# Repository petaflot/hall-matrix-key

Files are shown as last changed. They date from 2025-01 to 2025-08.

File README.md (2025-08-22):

# Hall Jumper Selector Matrix

A tool to help getting the configuration of hall sensors correct for any arbitrary 3-phase electric motor fitted with such devices. There are 6 possible arrangements, for direct and inverse rotations, and shifts relative to the phases. A 2x04 matrix is sufficient to select each arrangement by connecting adjacent pins.

A document that gives [more information on the arrangements](hall-jumper-matrix.pdf) can be found here.

## Hall Key

A simple yet elaborate mechanical device to ease the task of finding the correct jumper configuration ; special care was taken to reduce wear on the sliding contacts and thus extend the device life.
It looks pretty and is a somewhat mystical object that you can carry around everywhere you go.

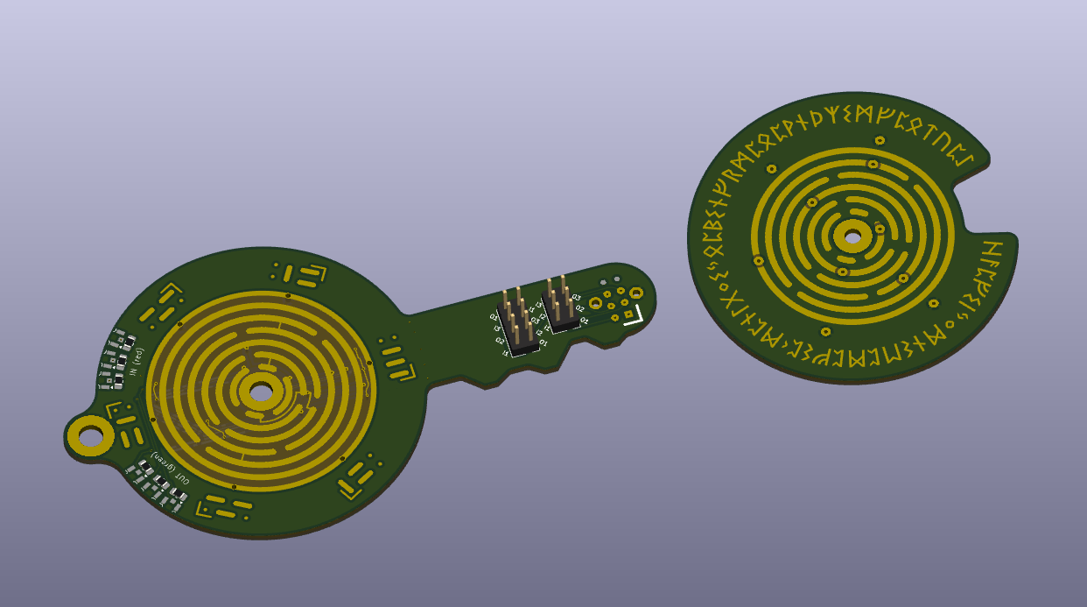
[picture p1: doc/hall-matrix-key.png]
Hall Key


***NOTE: In the above picture, the tracks are wrong ; this was fixed***

Datasheets of the required components are included.

### Note on the circular tracks

Considering the electrical and mechanical constraints, there is a unique solution to the arrangement ; therefore, it can be considered as a rune.

## Hall Matrix

A 2x04 pins jumper configuration matrix ; this project also includes a dedicated a solder jumper matrix footprint for Kicad. The pogo pins of the selector key go there, and they can be soldered once the correct configuration has been found.

***WARNING: footprint is not up-to-date with latest version of key!***

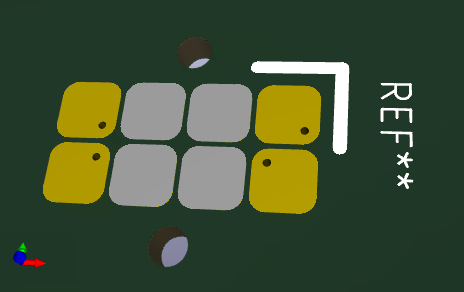
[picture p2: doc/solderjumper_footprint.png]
Solder jumper footprint


To ensure it can be accessed with the key, this footprint should go at the edge of the board.

An alternative is to use 2x04 header pins and regular jumpers ; this enables the configuration to be changed easily afterwards. In the case, connect to the key with a short cable.

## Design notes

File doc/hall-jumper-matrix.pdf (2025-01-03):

Feuille1

# Hall Sensor Selection Matrix

I1 | O2 | I3 | O1 ≃ | I1 | O2 | I3 | O1 | Norm
O1 | I2 | O3 | I1 | O1 | I2 | O3 | I1
I1 | O2 | I3 | O1 | | | | | Norm+1
O1 | I2 | O3 | I1
I1 | O2 I3 | O1 | Norm+2
O1 I2 | O3 I1
I1 | O2 | I3 | O1 | | | | | Rev-2
O1 | I2 | O3 I1
I1 | O2 | I3 | O1 | | | | | Rev-1
O1 I2 | O3 | I1
I1 | O2 I3 | O1 ≃ | I1 | O2 I3 | O1 | Rev
O1 | I2 | O3 | I1 | O1 | I2 | O3 | I1

Illegal positions (using 3 jumpers, symmetries not included)

Pin numbering, 2x04 header
2 | 4 | 6 | 8
1 | 3 | 5 | 7

Considering a motor fitted with 3 hall effect sensors for which the configuration is unkown, we want a compact and practical way to chose between each possible arrangement using jumpers. The jumpers must be fitted on at most two rows so they can stand on the edge of a PCB.

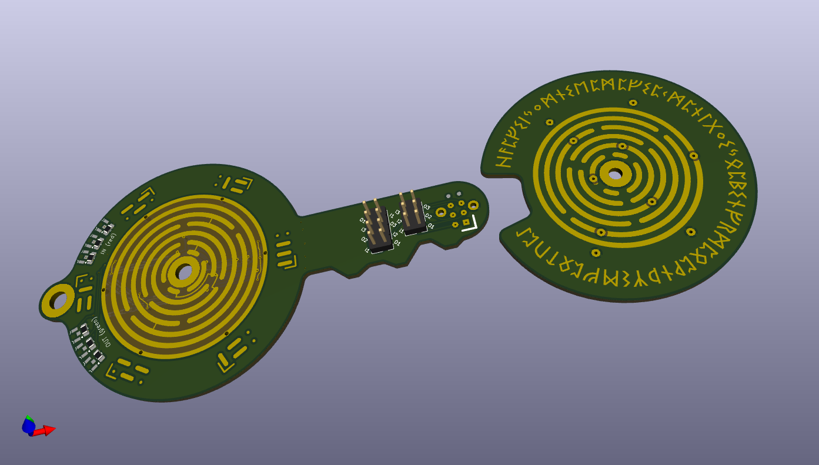
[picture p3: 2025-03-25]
hall-matrix-key/hall-matrix-key.png

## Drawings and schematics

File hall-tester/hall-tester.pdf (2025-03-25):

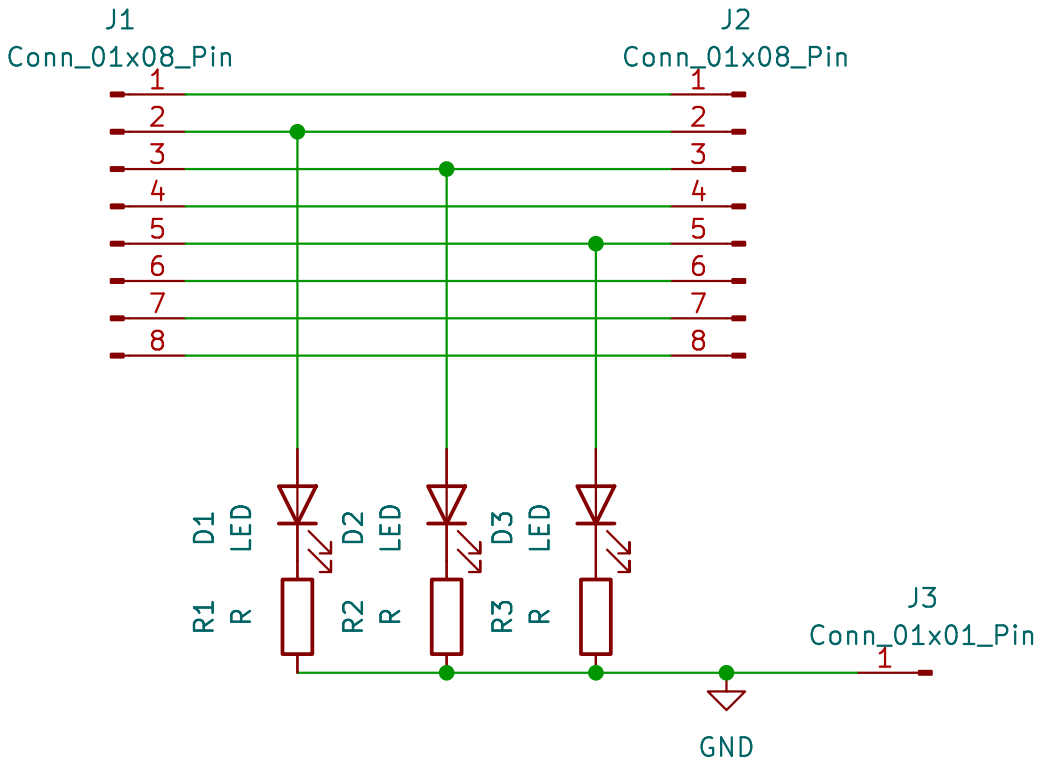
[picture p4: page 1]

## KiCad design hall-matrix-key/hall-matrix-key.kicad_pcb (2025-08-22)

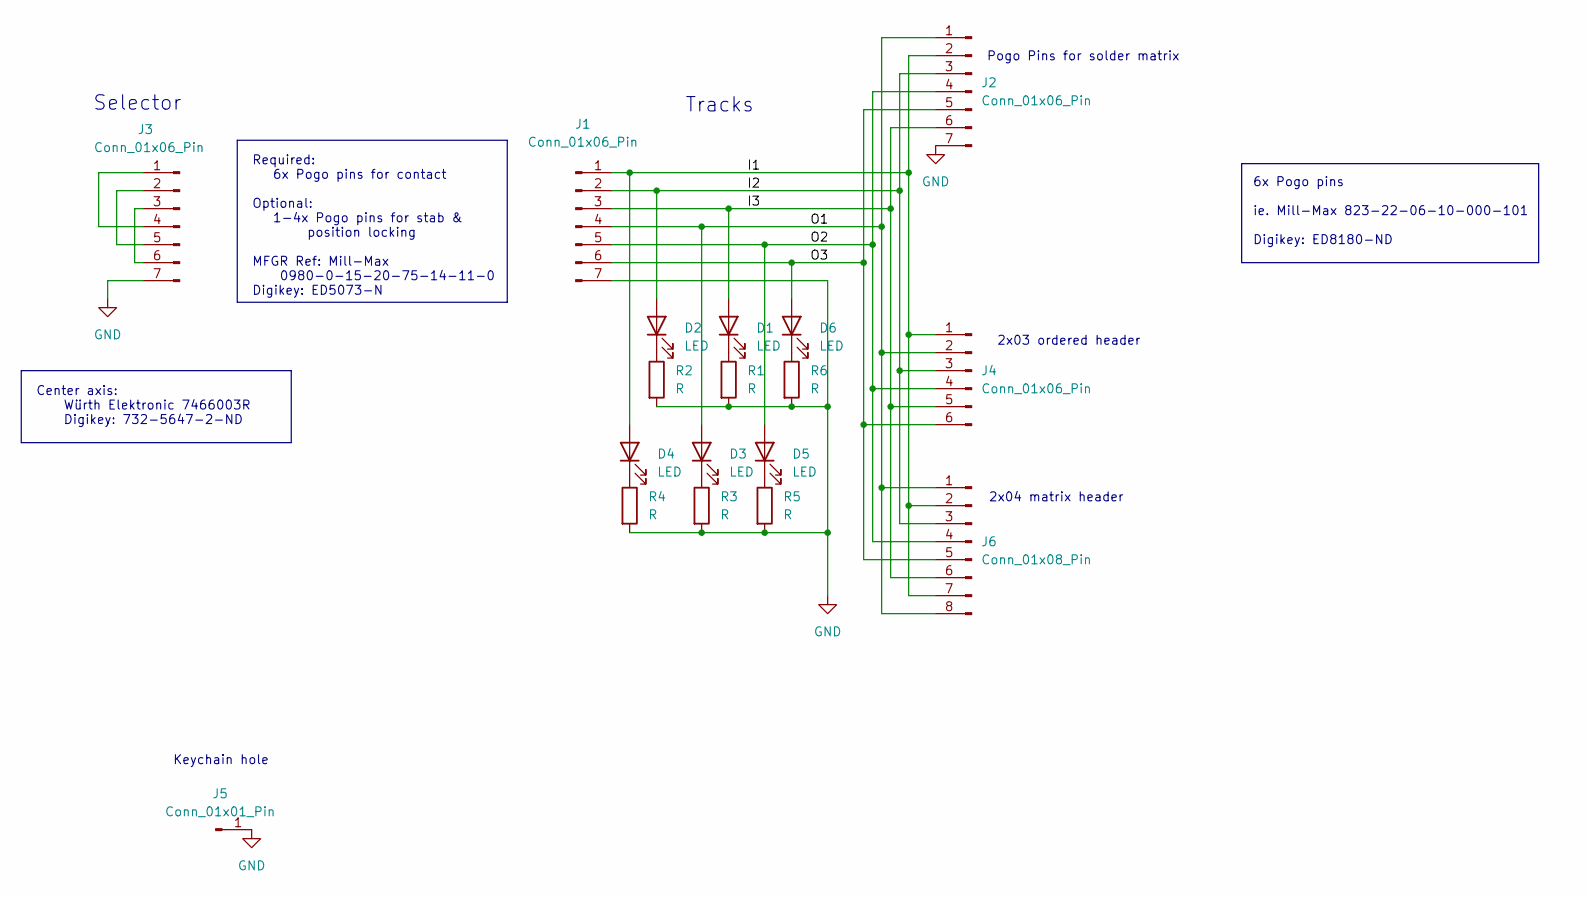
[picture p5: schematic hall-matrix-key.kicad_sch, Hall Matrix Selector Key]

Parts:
D1, D2, D3, D4, D5, D6: LED; LED_LiteOn_LTST-S326
J1: Conn_01x06_Pin; hall-matrix-selector-switch_base
J2: Conn_01x06_Pin; hall-matrix-selector_pogo
J3: Conn_01x06_Pin; hall-matrix-selector-switch_knob
J4: Conn_01x06_Pin; PinHeader_2x03_P2.54mm_Vertical
J5: Conn_01x01_Pin; keyhole
J6: Conn_01x08_Pin; PinHeader_2x04_P2.54mm_Vertical
R1, R2, R3, R4, R5, R6: R; R_0805_2012Metric_Pad1.20x1.40mm_HandSolder

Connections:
/I1: D4.2 (A), J1.1, J2.2, J4.1, J6.2, J6.7
/I2: D2.2 (A), J1.2, J2.3, J4.3, J6.3
/I3: D1.2 (A), J1.3, J2.6, J4.5, J6.6
/O1: D3.2 (A), J1.4, J2.1, J4.2, J6.1, J6.8
/O2: D5.2 (A), J1.5, J2.4, J4.4, J6.4
/O3: D6.2 (A), J1.6, J2.5, J4.6, J6.5
GND: J1.7, J2.7, J3.7, J5.1, R1.2, R2.2, R3.2, R4.2, R5.2, R6.2
unnamed: D1.1 (K), R1.1
unnamed: D2.1 (K), R2.1
unnamed: D3.1 (K), R3.1
unnamed: D4.1 (K), R4.1
unnamed: D5.1 (K), R5.1
unnamed: D6.1 (K), R6.1
unnamed: J3.1, J3.4
unnamed: J3.2, J3.5
unnamed: J3.3, J3.6

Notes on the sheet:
Keychain hole
2x03 ordered header
Center axis: Würth Elektronic 7466003R Digikey: 732-5647-2-ND
Pogo Pins for solder matrix
6x Pogo pins ie. Mill-Max 823-22-06-10-000-101 Digikey: ED8180-ND
2x04 matrix header
Selector
Required: 6x Pogo pins for contact Optional: 1-4x Pogo pins for stab & position locking MFGR Ref: Mill-Max 0980-0-15-20-75-14-11-0 Digikey: ED5073-N
Tracks

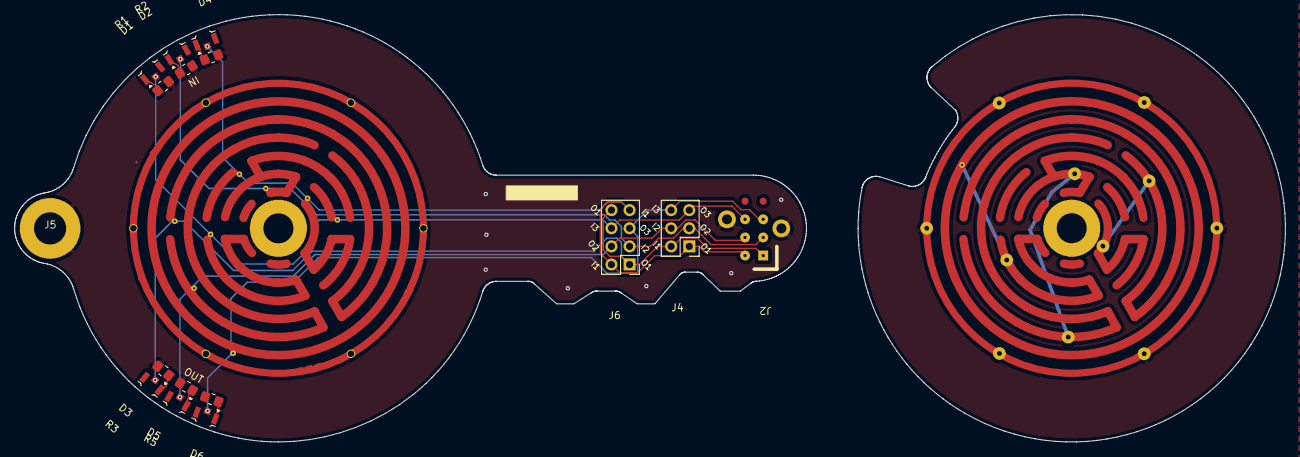
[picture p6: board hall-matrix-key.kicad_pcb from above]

Board: 2 copper layers, 110.9 x 59.9 mm, 18 parts (0 on the bottom side), 16 nets.

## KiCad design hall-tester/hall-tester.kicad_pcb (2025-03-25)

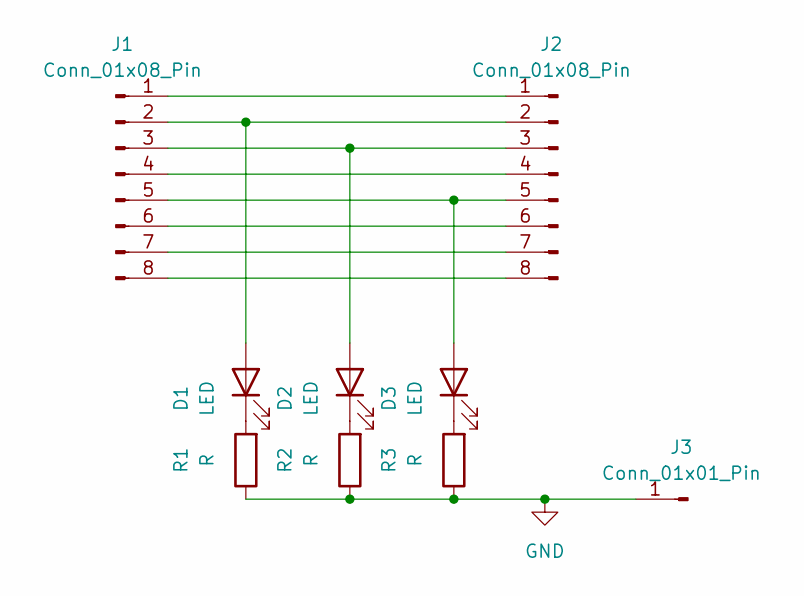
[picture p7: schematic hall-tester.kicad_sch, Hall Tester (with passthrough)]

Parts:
D1, D2, D3: LED; LED_Kingbright_APDA3020VBCD
J1: Conn_01x08_Pin; PinHeader_2x04_P2.54mm_Horizontal
J2: Conn_01x08_Pin; EdgeHeader-2.54_2x04
J3: Conn_01x01_Pin; PinHeader_1x01_P2.54mm_Horizontal
R1, R2, R3: R; R_0805_2012Metric_Pad1.20x1.40mm_HandSolder

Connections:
GND: J3.1, R1.1, R2.1, R3.1
unnamed: D1.2 (A), J1.2, J2.2
unnamed: D1.1 (K), R1.2
unnamed: D2.2 (A), J1.3, J2.3
unnamed: D2.1 (K), R2.2
unnamed: D3.2 (A), J1.5, J2.5
unnamed: D3.1 (K), R3.2
unnamed: J1.1, J2.1
unnamed: J1.4, J2.4
unnamed: J1.6, J2.6
unnamed: J1.7, J2.7
unnamed: J1.8, J2.8

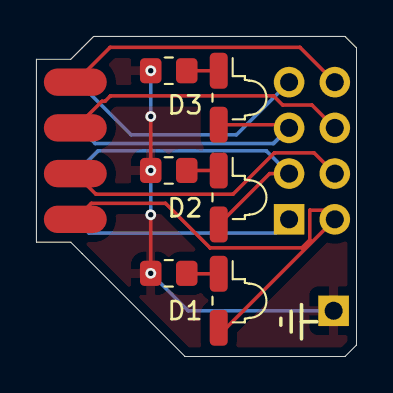
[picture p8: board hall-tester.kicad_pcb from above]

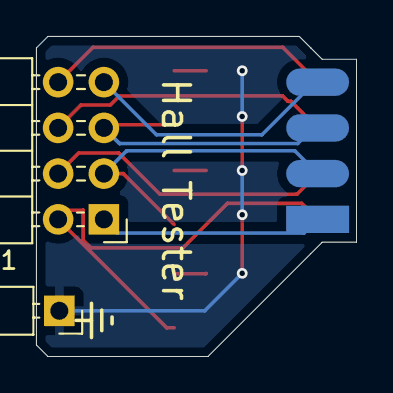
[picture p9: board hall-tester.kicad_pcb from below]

Board: 2 copper layers, 17.8 x 17.8 mm, 9 parts (3 on the bottom side), 12 nets.

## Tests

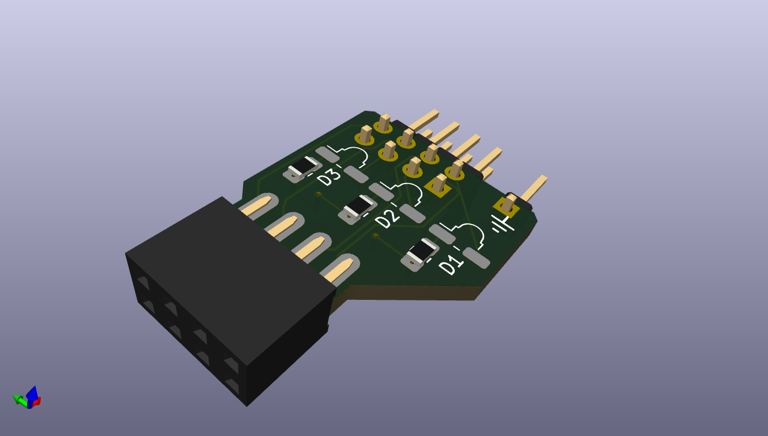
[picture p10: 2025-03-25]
hall-tester/hall-tester-top.png

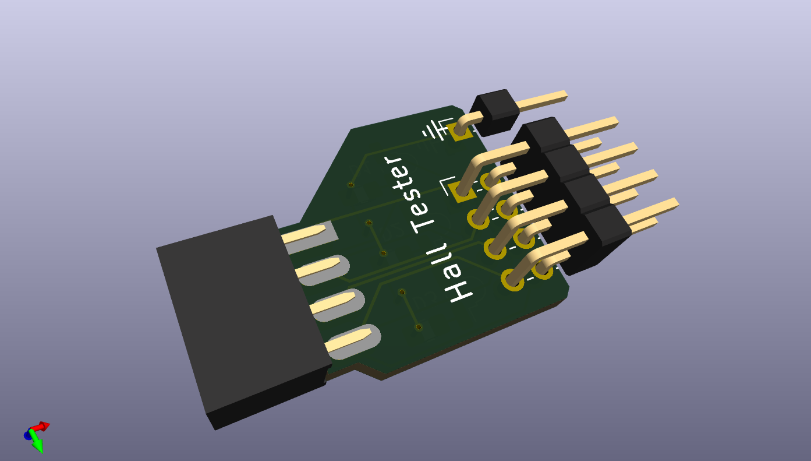
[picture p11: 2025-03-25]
hall-tester/hall-tester-bottom.png

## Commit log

2025-01-03 Ready for fabrication
    [hall-jumper-matrix.ods, hall-matrix-key.kicad_pcb, hall-matrix-key.kicad_sch]
2025-03-25 stale changes
    [hall-matrix-key.kicad_pcb, hall-matrix-key.kicad_sch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]
2025-07-25 second batch with corrections (purple)
    [hall-jumper-matrix.ods, hall-matrix-key.kicad_pcb, hall-matrix-key.kicad_sch]
2025-07-25 second batch production, should be fixed
    50 (?) pieces ordered for WHY2025, purple/white/ENIG
    [hall-matrix-key.kicad_pcb]
2025-08-22 update for second, corrected batch.
    series manufactured for WHY2025 have one pogo hole too small on the
    rotator
    [hall-matrix-key.kicad_pcb]
